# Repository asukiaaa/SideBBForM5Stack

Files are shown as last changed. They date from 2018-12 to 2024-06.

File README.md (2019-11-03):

# SideBBForM5Stack

An stack for M5Stack to use bread board easier.

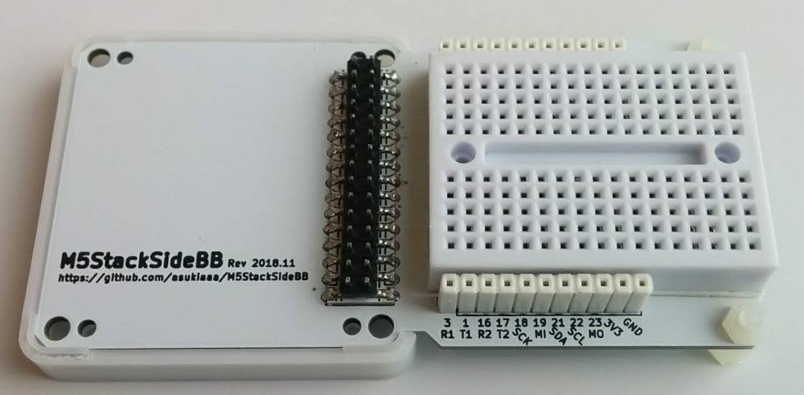
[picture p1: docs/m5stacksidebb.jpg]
m5stacksidebb

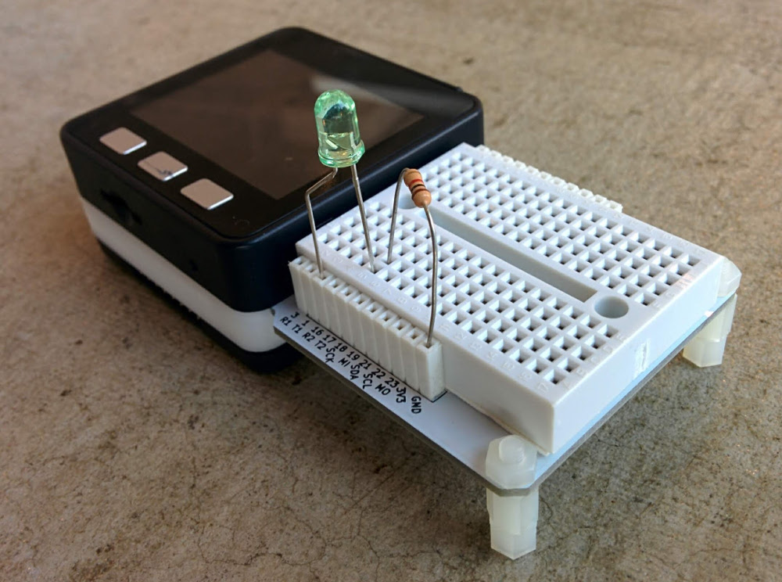
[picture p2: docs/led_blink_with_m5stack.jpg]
led_blink_with_m5stack


# Where to buy

[SideBBForM5Stack - Switch Science](https://www.switch-science.com/catalog/4098/)

# License

MIT

# References

- [M5Stackの信号線をブレッドボードで扱いやすくするStackを作ってみた](https://asukiaaa.blogspot.com/2018/11/m5stacksidebb.html)
- [PartsandCircuits/M5Stack-3DPrintFiles](https://github.com/PartsandCircuits/M5Stack-3DPrintFiles)
- [DIY Mini Proto Board](http://forum.m5stack.com/topic/59/diy-mini-proto-board)

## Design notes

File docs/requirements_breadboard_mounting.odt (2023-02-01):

Remove connectors on a bread board if it has hooks.

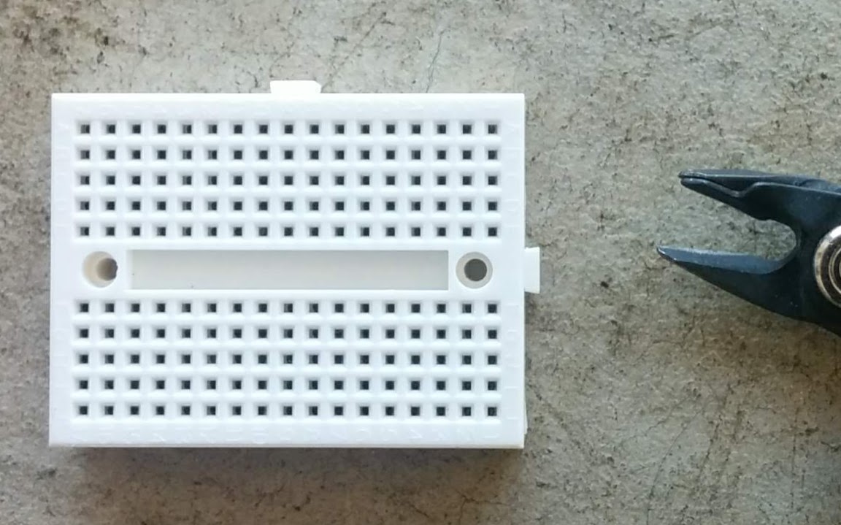
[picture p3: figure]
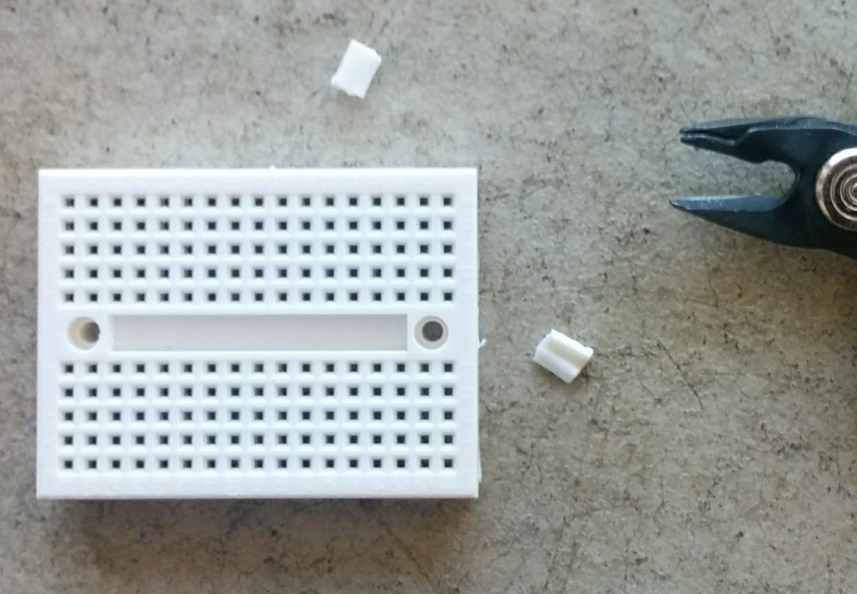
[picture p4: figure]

Put the bread board between pin sockets.

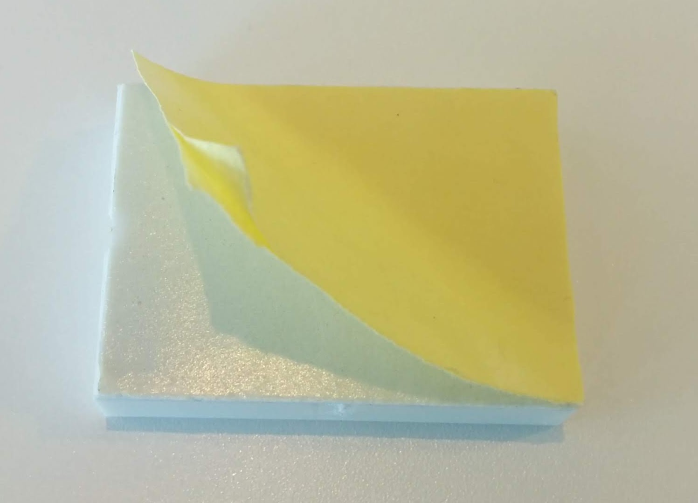
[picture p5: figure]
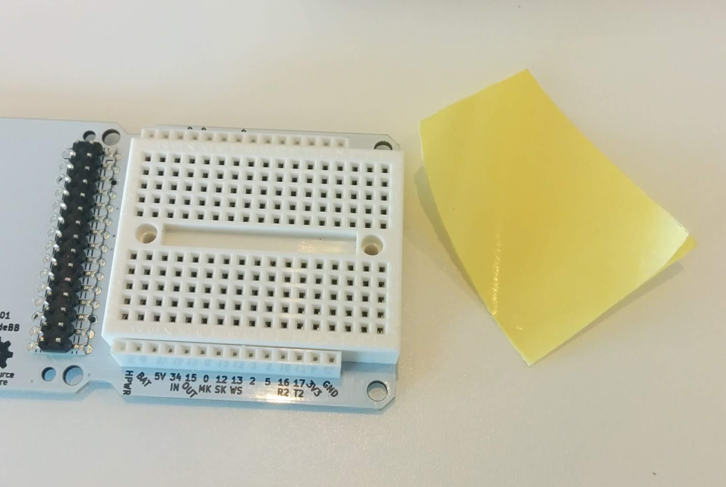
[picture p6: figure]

Make sure the hole position of pin sockets and bread board are parallel.

Be careful not to shift over 0.7mm.

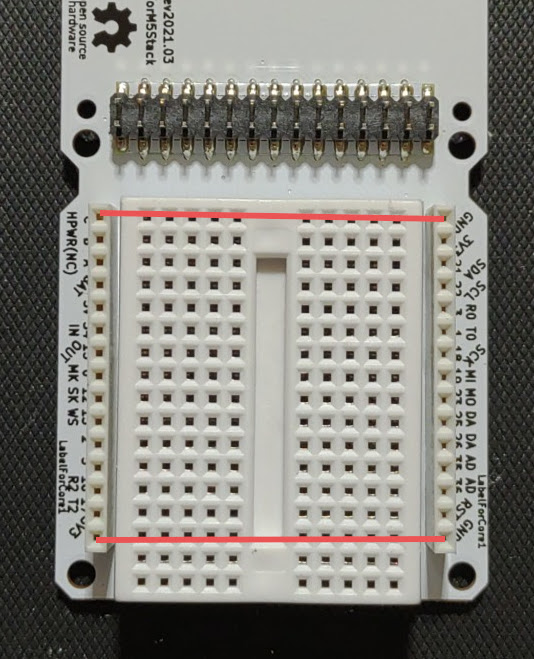
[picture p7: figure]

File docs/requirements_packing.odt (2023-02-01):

Put a frame on PCB.(Make sure that wall that has a depression become inside of PCB.)

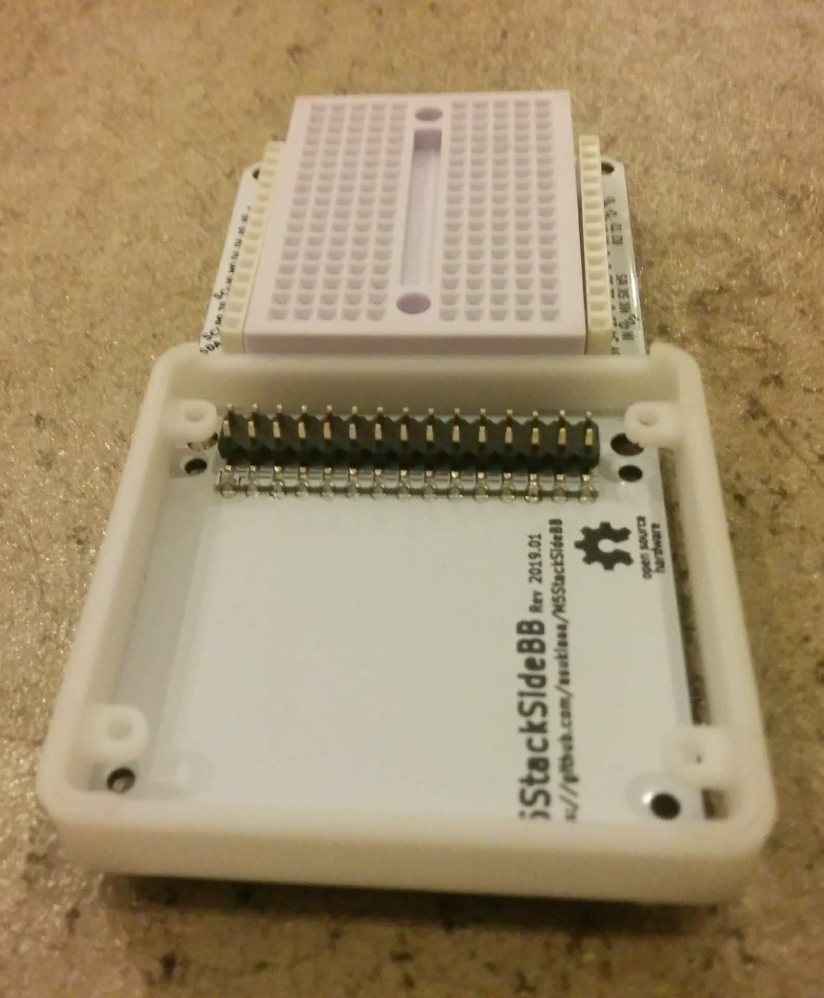
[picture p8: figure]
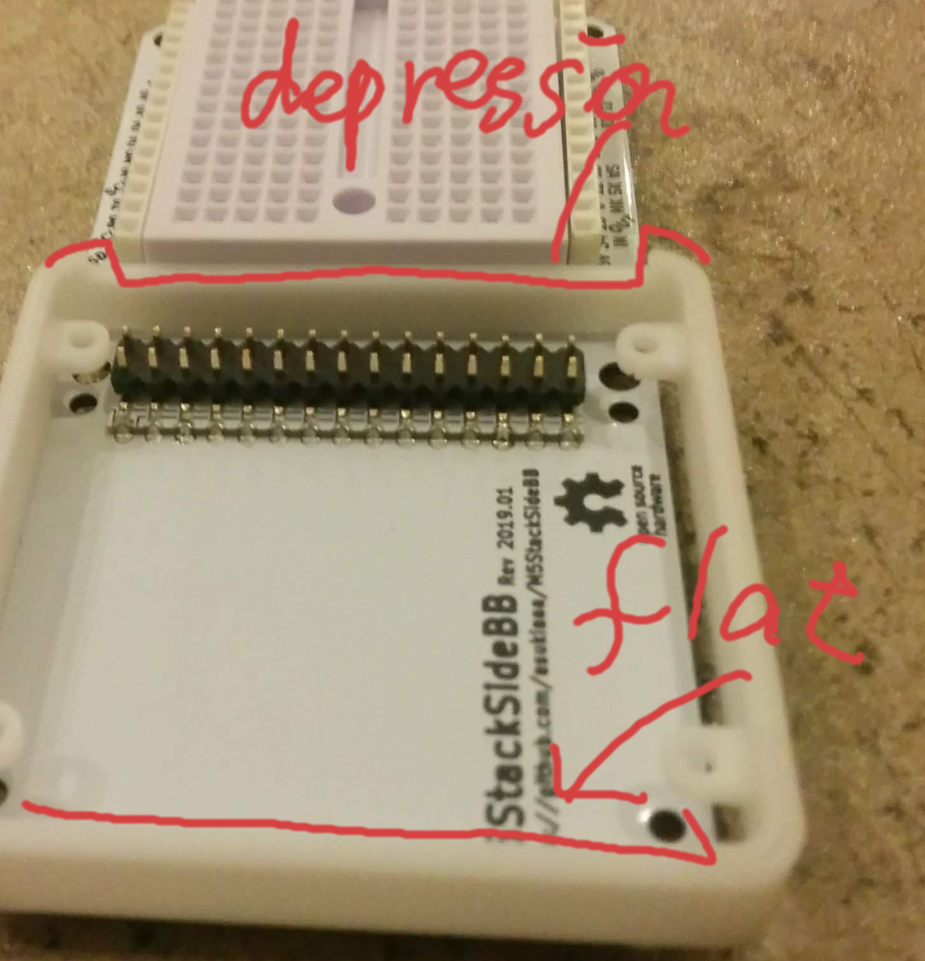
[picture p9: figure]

Put nuts(M3 *2) and spacers(M3 5mm * 2, M3 7mm * 2) inside of a frame.

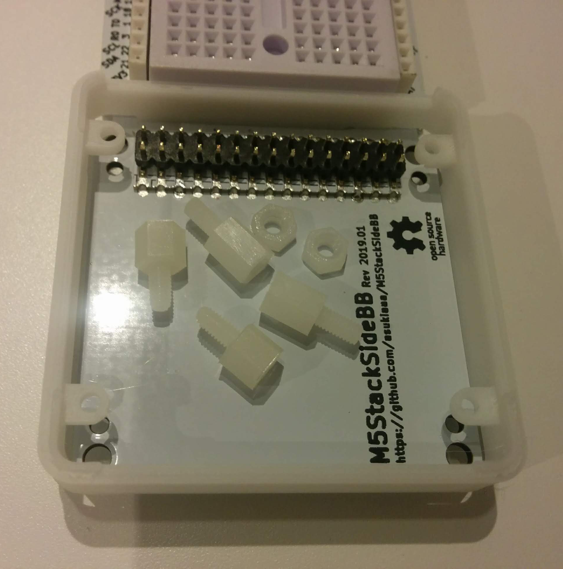
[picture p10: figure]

Put the pcb, frame, nuts and spacers into bug.

No need to close with some tape

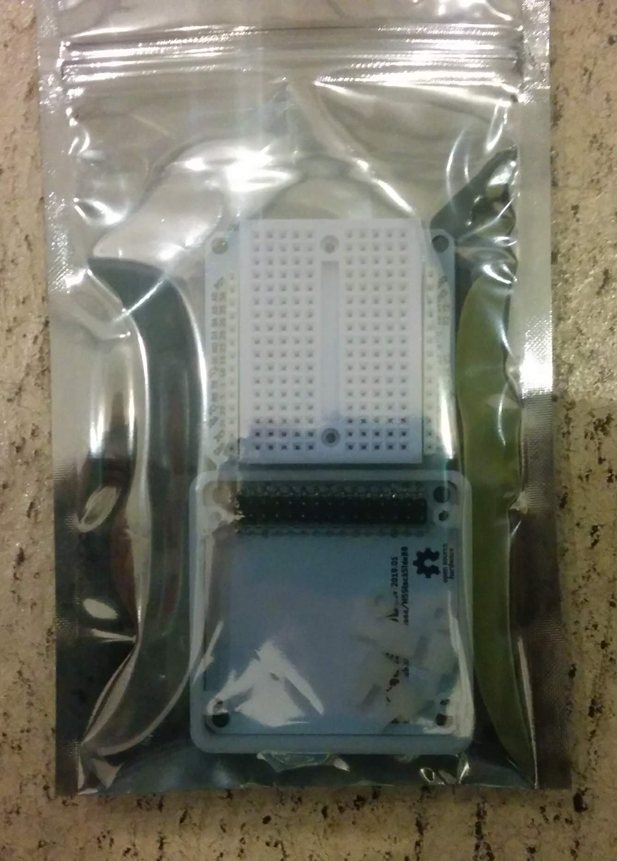
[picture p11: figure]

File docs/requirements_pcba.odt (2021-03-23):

M5StackSideBB Requirements.

Remove redundant copper from the spacer PCB.

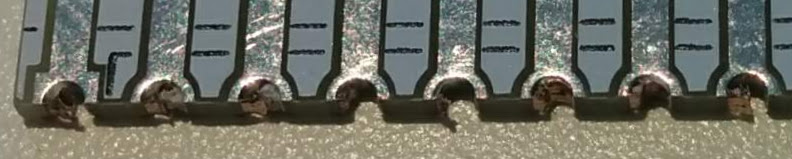
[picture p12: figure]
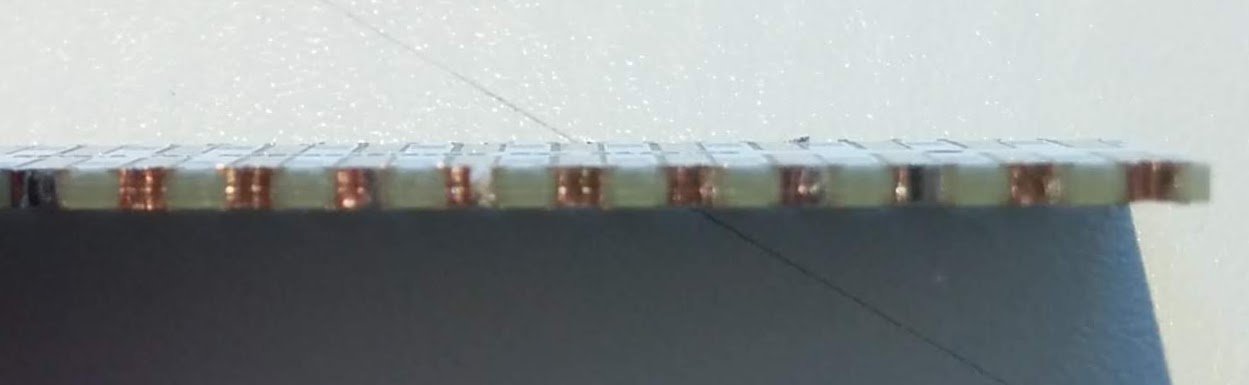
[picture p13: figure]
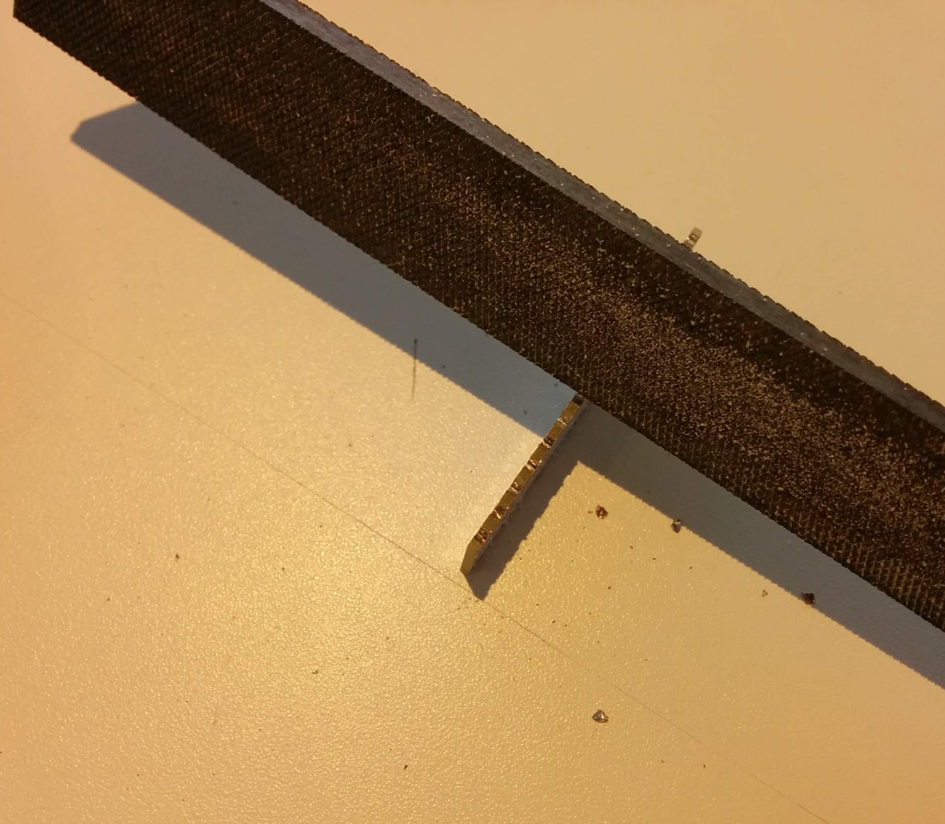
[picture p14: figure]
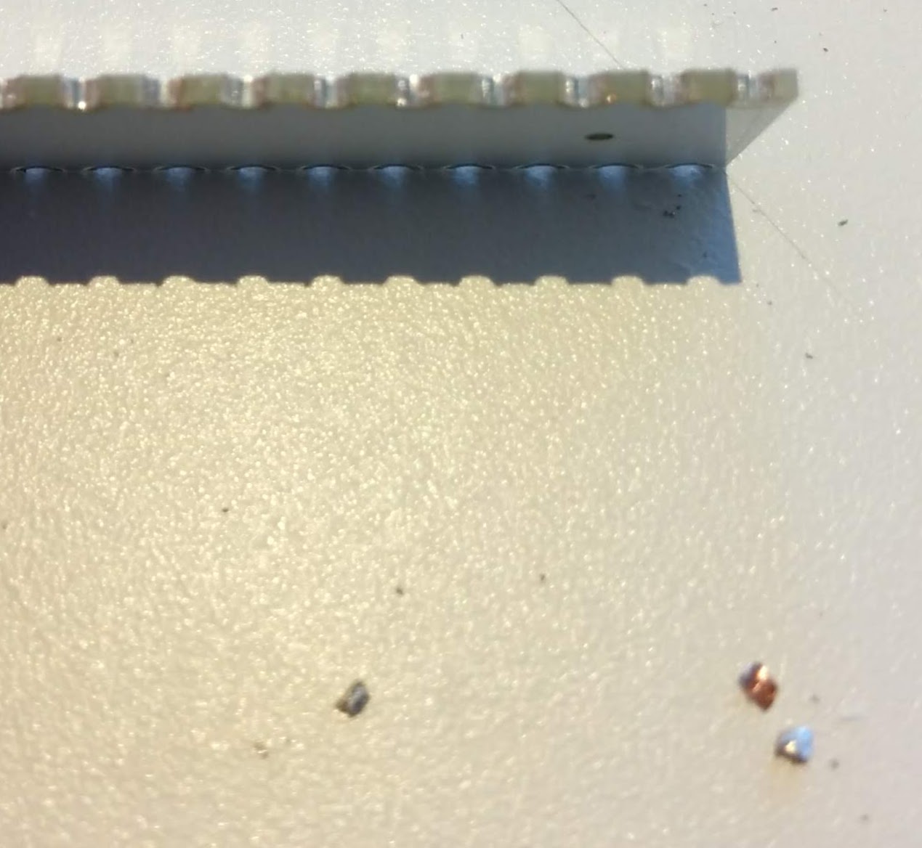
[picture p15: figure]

Adjust the hole positions of the spacer PCB and the main PCB, then solder to join them.

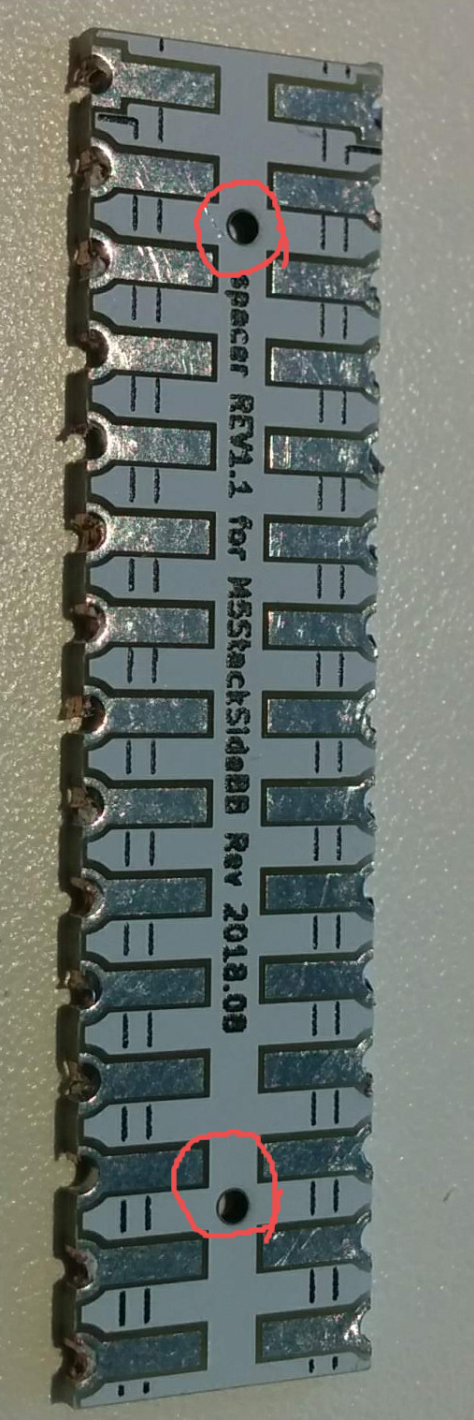
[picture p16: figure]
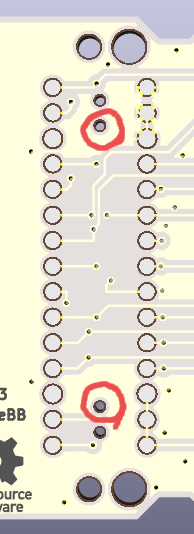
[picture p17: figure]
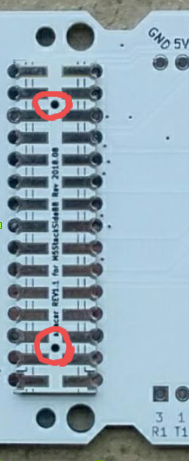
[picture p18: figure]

After that solder header to top, socket to bottom.

Put both pin sockets to inside of PCB as well as possible.

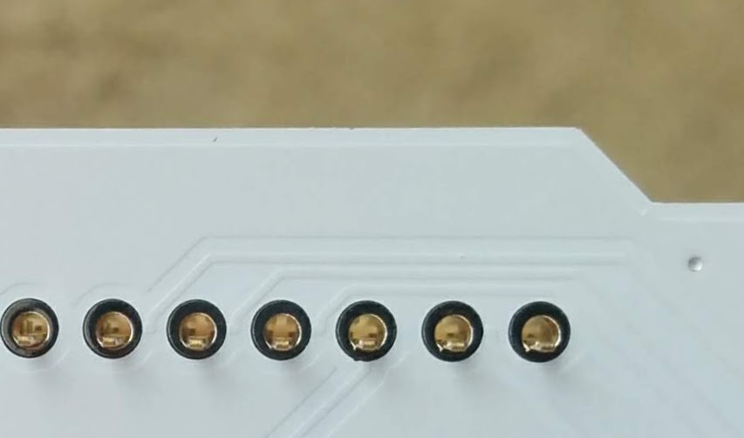
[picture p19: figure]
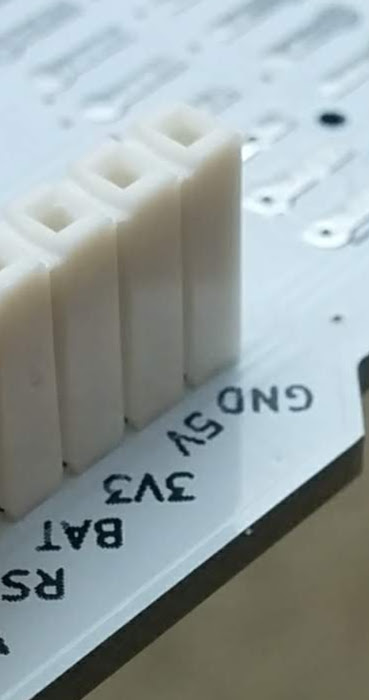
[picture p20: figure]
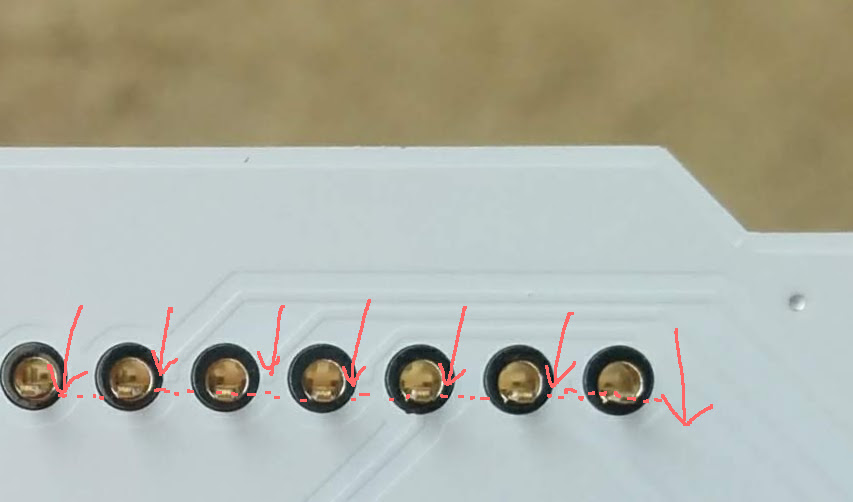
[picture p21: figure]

Finish images (Rev2021.03 uses 1x15 pinsocket)

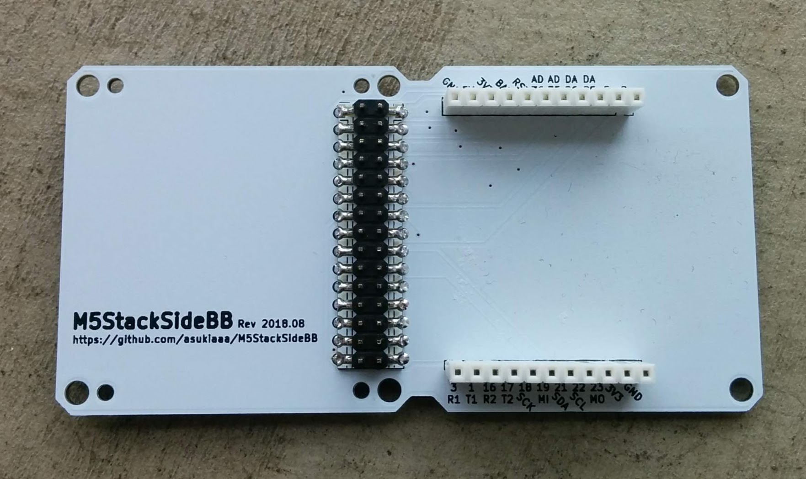
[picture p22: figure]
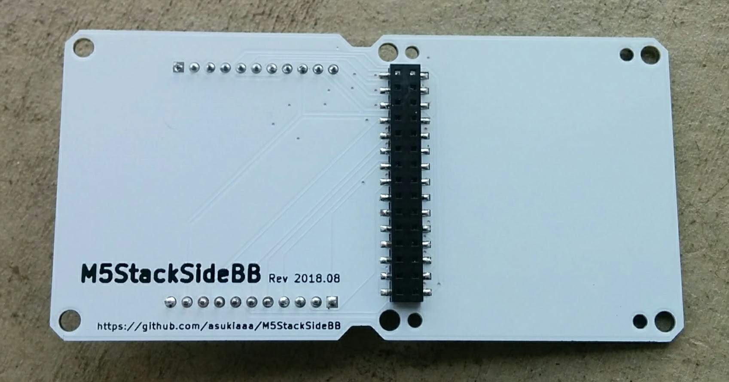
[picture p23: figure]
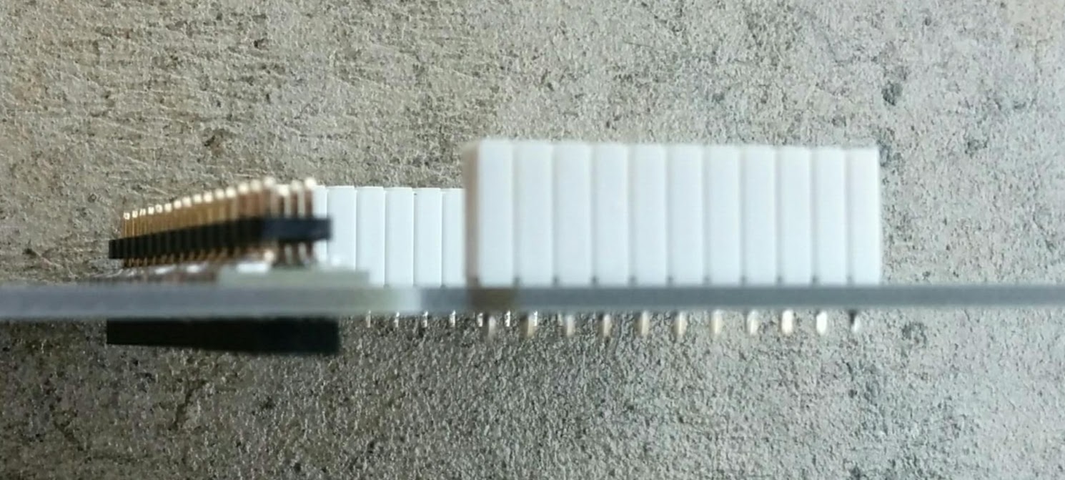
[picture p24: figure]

i

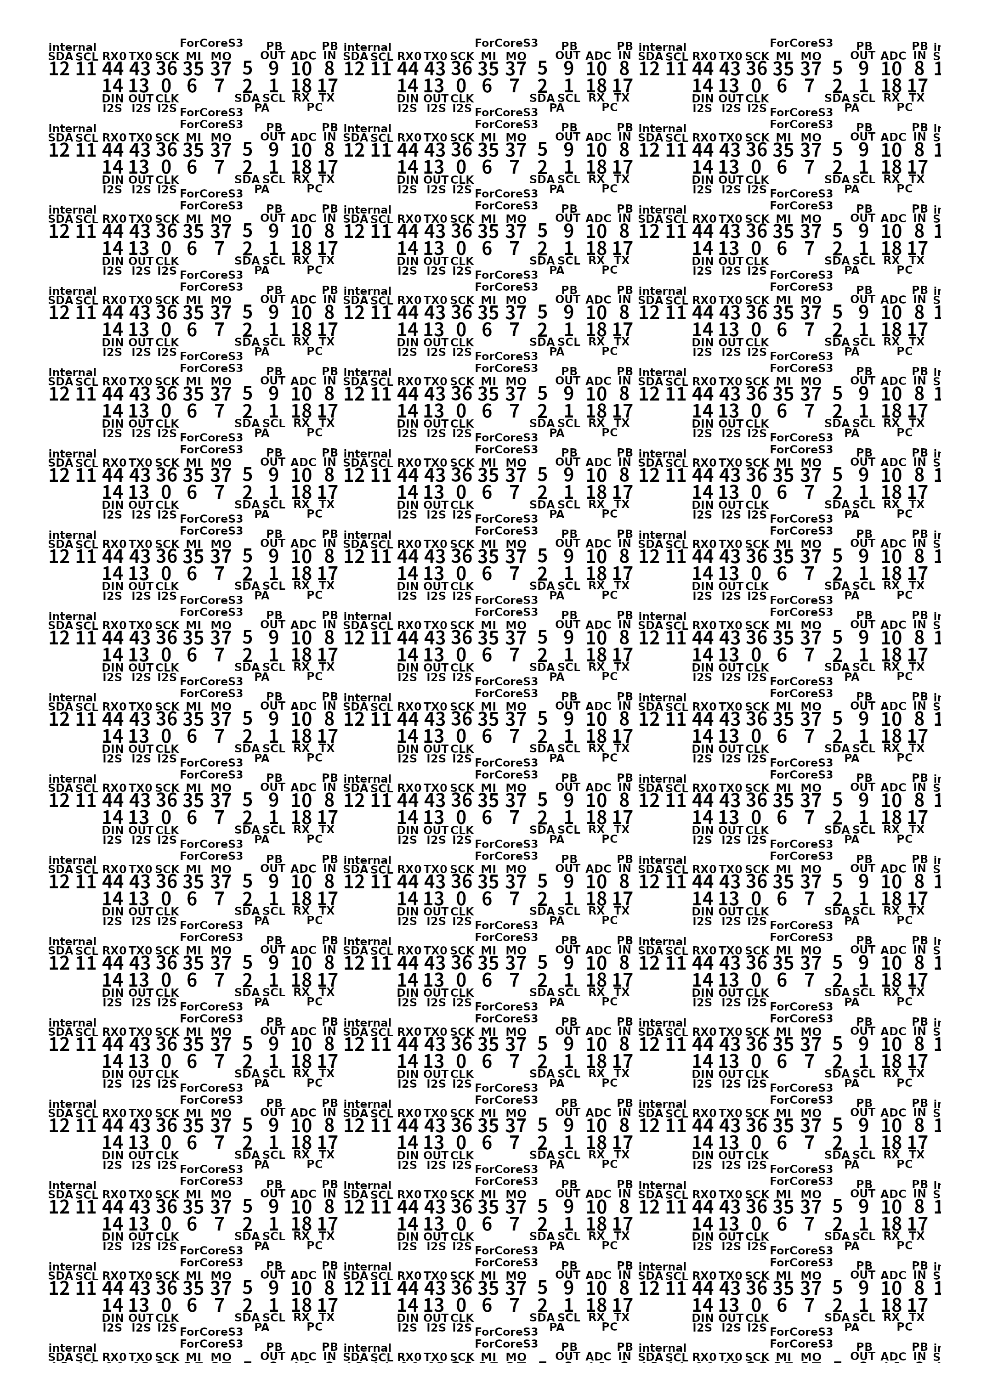
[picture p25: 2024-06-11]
docs/2148x3048px_tiles_of_lauson_sticker_l_2148x3048px_89x127mm_for_core_s3.png

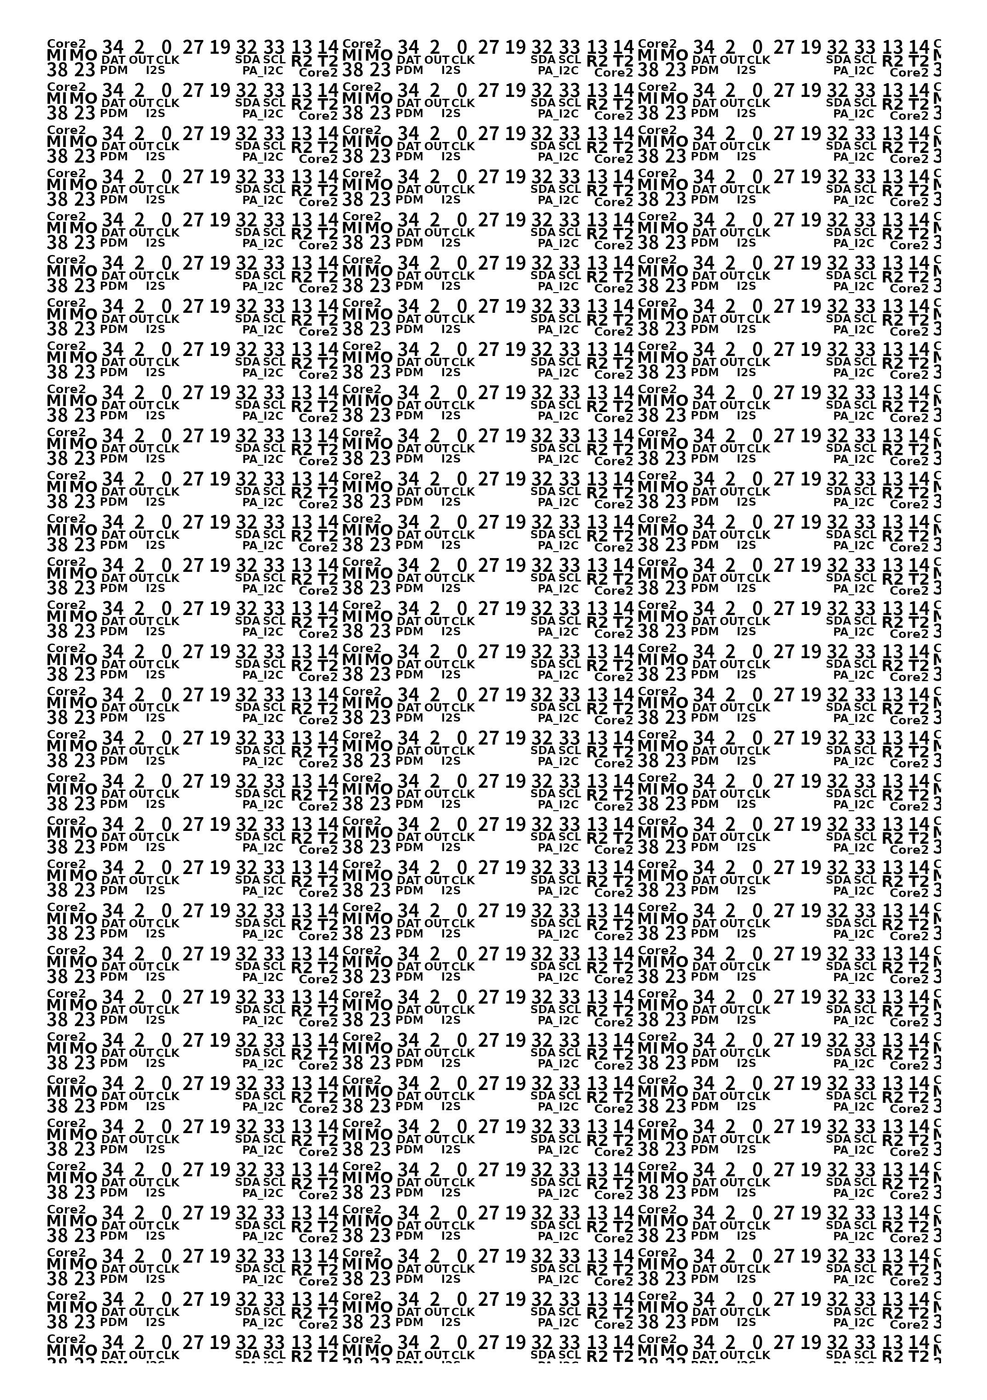
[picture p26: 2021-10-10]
docs/2148x3048px_tiles_for_core2.png

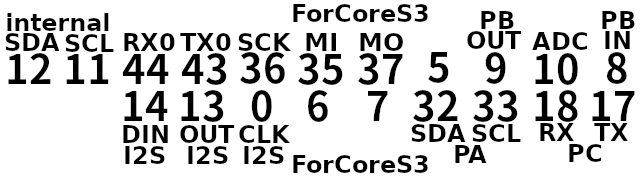
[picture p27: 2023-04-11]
docs/lauson_sticker_l_2148x3048px_89x127mm_for_core_s3.png

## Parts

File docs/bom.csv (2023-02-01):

Name | Number | Url | Memo
Main PCB (100x50x1.6mm) | 1 | Attached main
Spacer PCB (8.7x37.3x1.0mm) | 1 | Attached spacer
M5 Stack New(ver2021 about 6.5mm height) Header | 1 | https://shop.m5stack.com/collections/m5-accessories/products/2-%E2%9C%96-15-pinheader-bus-socket-smd-for-13-2-module-10-sets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
M5 Stack Legacy(before ver2021) Socket | 1 | https://shop.m5stack.com/collections/m5-accessories/products/2x15-pin-headers-socket
2.54mm 1x15 white socket | 2 | http://akizukidenshi.com/catalog/g/gC-11571/ | I don't mind the vendor.
MniBreadBoard white | 1 | https://ja.aliexpress.com/item/32972035565.html | Use this shop because quality of breadboard on Elecrow store was not good (on 2018.)
M3 5mm Spacer | 2 | https://ja.aliexpress.com/item/100pcs-M3-Nylon-Hexagonal-Pillar-Female-and-Male-Standoff-Spacer-M3x5-6mmm-M3x6-6mm-M3x7-6mm/32811270025.html | I don't mind the vendor.
M3 7mm Spacer | 2 | https://ja.aliexpress.com/item/32957035974.html | I don't mind the vendor.
M3 Nut | 2 | https://ja.aliexpress.com/item/100pcs-M3-Nylon-Hexagonal-Pillar-Female-and-Male-Standoff-Spacer-M3x5-6mmm-M3x6-6mm-M3x7-6mm/32811270025.html | I don't mind the vendor.

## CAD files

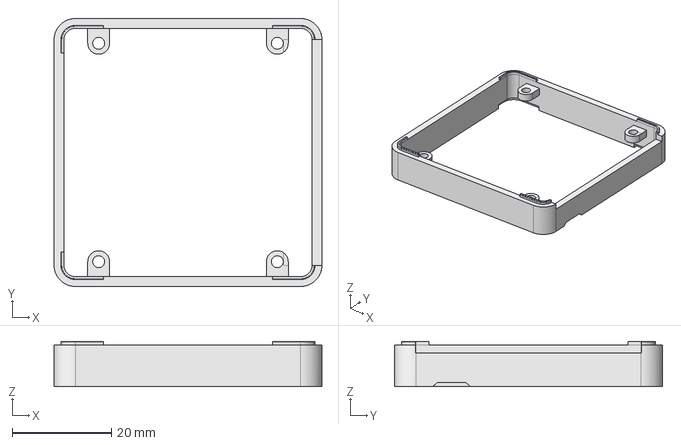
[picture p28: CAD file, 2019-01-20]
case/narrow/M5StackSideBBCase.fcstd
54.0 x 54.0 x 9.10 mm

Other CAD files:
case/zotrax_m200p/M5StackSideBBCase.fcstd
case/narrow/M5StackSideBBCase.stl
case/zotrax_m200p/M5StackSideBBCase.stl

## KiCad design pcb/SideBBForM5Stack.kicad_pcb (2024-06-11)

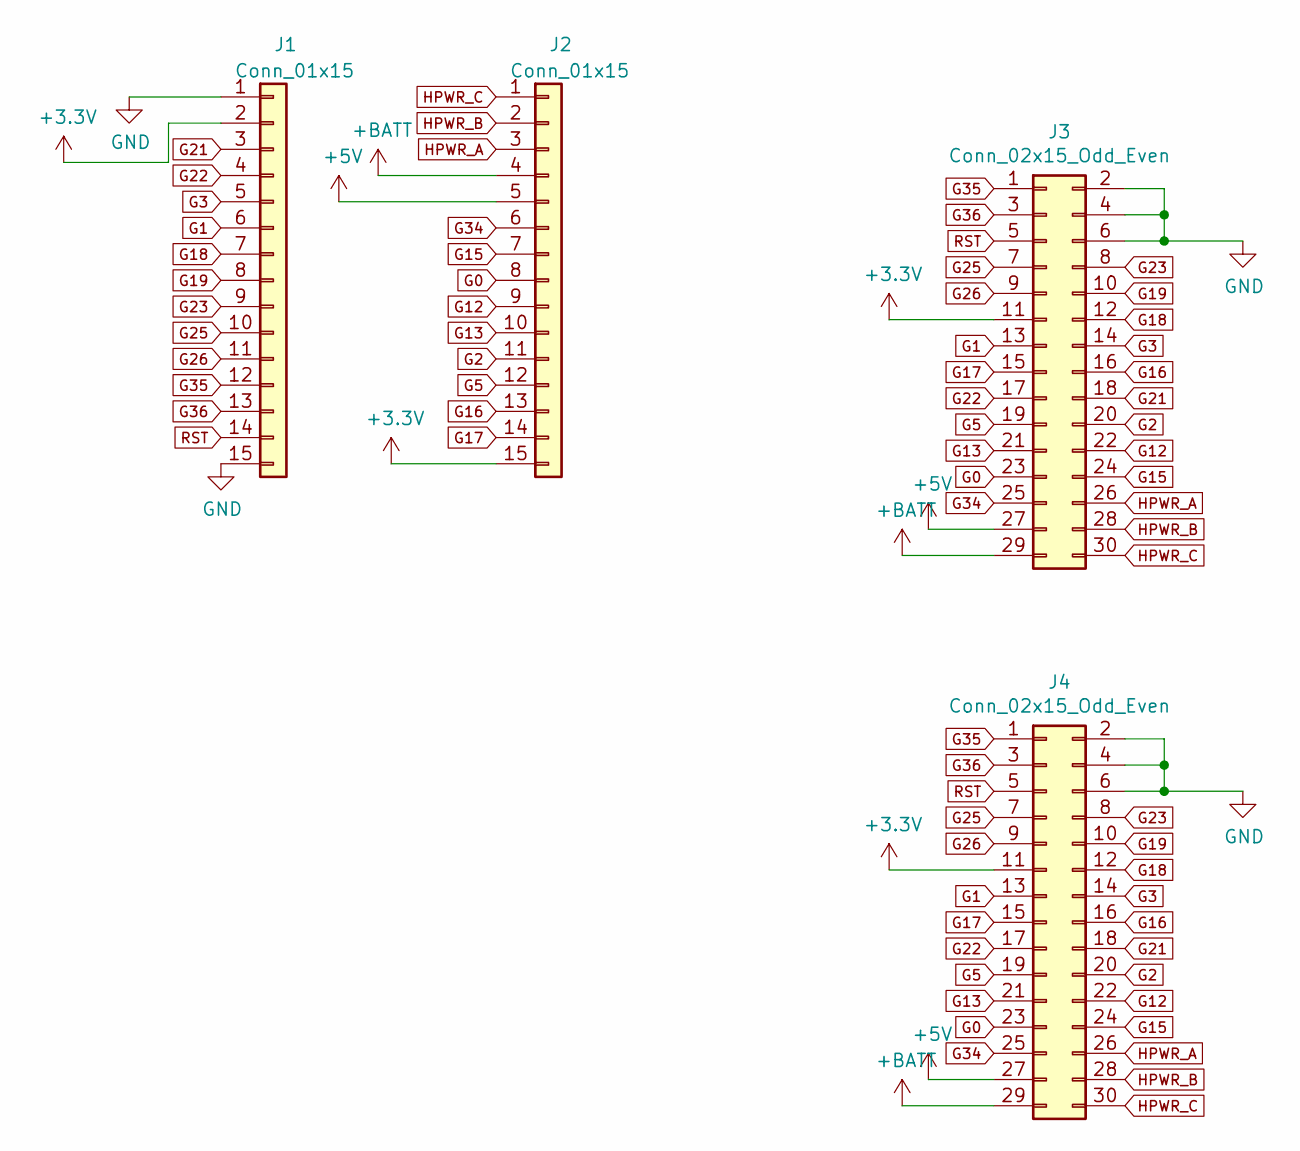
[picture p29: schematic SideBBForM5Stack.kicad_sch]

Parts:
J1, J2: Conn_01x15; PinSocket_1x15_P2.54mm_Vertical_without_silk
J3: Conn_02x15_Odd_Even; PinHeader_2x15_P2.54mm_M5Stack_SpacerPCB_pads
J4: Conn_02x15_Odd_Even; PinSocket_2x15_P2.54mm_Vertical_SMD_just_for_M5Stack_bottom

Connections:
+3V3: J1.2, J2.15, J3.11, J4.11
+5V: J2.5, J3.27, J4.27
+BATT: J2.4, J3.29, J4.29
G0: J2.8, J3.23, J4.23
G1: J1.6, J3.13, J4.13
G2: J2.11, J3.20, J4.20
G3: J1.5, J3.14, J4.14
G5: J2.12, J3.19, J4.19
G12: J2.9, J3.22, J4.22
G13: J2.10, J3.21, J4.21
G15: J2.7, J3.24, J4.24
G16: J2.13, J3.16, J4.16
G17: J2.14, J3.15, J4.15
G18: J1.7, J3.12, J4.12
G19: J1.8, J3.10, J4.10
G21: J1.3, J3.18, J4.18
G22: J1.4, J3.17, J4.17
G23: J1.9, J3.8, J4.8
G25: J1.10, J3.7, J4.7
G26: J1.11, J3.9, J4.9
G34: J2.6, J3.25, J4.25
G35: J1.12, J3.1, J4.1
G36: J1.13, J3.3, J4.3
GND: J1.1, J1.15, J3.2, J3.4, J3.6, J4.2, J4.4, J4.6
HPWR_A: J2.3, J3.26, J4.26
HPWR_B: J2.2, J3.28, J4.28
HPWR_C: J2.1, J3.30, J4.30
RST: J1.14, J3.5, J4.5

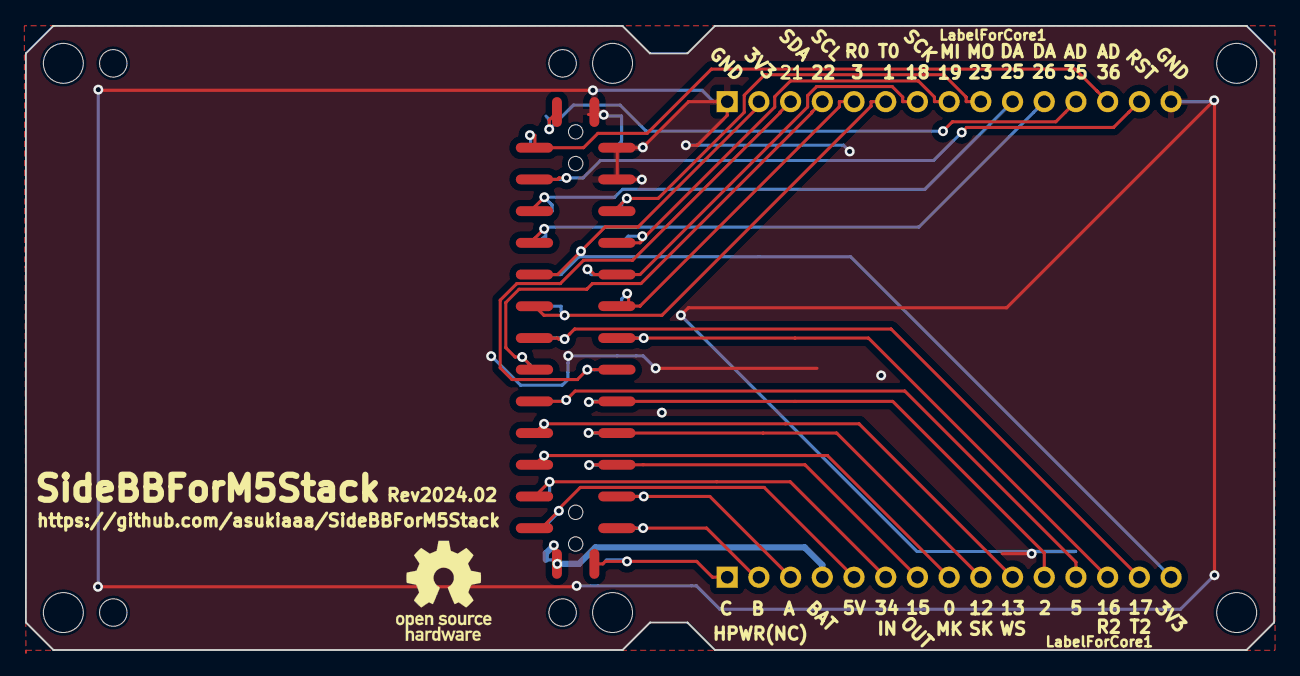
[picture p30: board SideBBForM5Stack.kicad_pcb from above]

Board: 2 copper layers, 100.0 x 50.0 mm, 14 parts (1 on the bottom side), 28 nets.

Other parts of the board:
REF1, REF4, REF5, REF6, REF9, REF10: MountingHole_3.2mm_M3
REF2, REF3, REF7, REF8: MountingHole_2.2mm_M2

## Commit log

2018-06-16 Create schematic of M5StackSideBB
    [M5StackSideBB.kicad_pcb, M5StackSideBB.sch]
2018-06-18 Put components and holes as pcb
    [M5StackSideBB.kicad_pcb, M5StackSideBB.sch]
2018-06-18 Draw lines with using autorouter
    [M5StackSideBB.kicad_pcb]
2018-06-18 Update schema and put silk texts
    [M5StackSideBB.kicad_pcb, M5StackSideBB.sch]
2018-06-19 Create gerber files to order
    [M5StackSideBB-B.Cu.gbr, M5StackSideBB-B.Mask.gbr, M5StackSideBB-B.Paste.gbr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]
2018-06-25 Create case in rough size
    [M5StackSideBBCase.fcstd]
2018-06-26 Adjust size by referencing M5Stack
    [M5StackSideBBCase.fcstd]
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2018-06-28 Update sylk layout of names about pins
    [M5StackSideBB.kicad_pcb, M5StackSideBBCase.fcstd]
2018-06-29 Update size of case
    [M5StackSideBBCase.fcstd, M5StackSideBBCase.stl]
2018-06-29 Update design of corner
    [M5StackSideBBCase.fcstd, M5StackSideBBCase.stl]
2018-06-30 Make top corner thicker and put inside
    [M5StackSideBBCase.fcstd, M5StackSideBBCase.stl]
2018-07-04 Change mounting hole size to M3 from M2.5
    [M5StackSideBB.kicad_pcb]
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2018-07-06 Create spacer pcb roughly
    [spacer_pcb.kicad_pcb, spacer_pcb.sch]
2018-07-07 Update connecting hole position between pcb and spacer pcb
    [M5StackSideBB.kicad_pcb, spacer_pcb.kicad_pcb]
2018-07-07 Update revision and gerbers
    [M5StackSideBB-B.Cu.gbr, M5StackSideBB-B.Mask.gbr, M5StackSideBB-B.Paste.gbr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]
2018-07-12 Change case height lower
    [M5StackSideBBCase.fcstd]
2018-07-13 Change low length shorter and top hook smaller
    [M5StackSideBBCase.fcstd]
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2018-07-17 Remove redundant reference on front fab
    [M5StackSideBB.kicad_pcb]
2018-07-18 Change space for breadborard narrower
    [M5StackSideBB.kicad_pcb]
2018-07-19 Change pinsocket on schema
    [M5StackSideBB.sch]
2018-07-19 Correct pin assign for bottom socket
    [M5StackSideBB.sch]
2018-07-20 Update component and its position on pcb
    [M5StackSideBB.kicad_pcb, M5StackSideBB.sch]
2018-07-20 Assign new footprint for spacer
    [spacer_pcb.kicad_pcb, spacer_pcb.sch]
2018-07-20 Update route of pcb
    [M5StackSideBB.kicad_pcb]
2018-07-21 Export gerber files to order rev 1.2
    [M5StackSideBB-B.Cu.gbr, M5StackSideBB-B.Mask.gbr, M5StackSideBB-B.Paste.gbr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]
2018-07-24 Expand clearance of top and bottom for case
    [M5StackSideBBCase.fcstd, M5StackSideBBCase.stl]
2018-07-26 Change back logo size larger
    [M5StackSideBB.kicad_pcb]
2018-07-27 Correct revision of spacer_pcb
    [spacer_pcb.kicad_pcb]
2018-10-05 Change innner size smaller
    [M5StackSideBBCase.fcstd, M5StackSideBBCase.stl]
2018-11-09 Update design for production
    [M5StackSideBB-B.Cu.gbr, M5StackSideBB-B.Mask.gbr, M5StackSideBB-B.Paste.gbr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]
2018-11-09 Change pad position as Rev 2018.11
    [M5StackSideBB-B.Cu.gbr, M5StackSideBB-B.Mask.gbr, M5StackSideBB-B.Paste.gbr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]
2018-11-17 Change bottom space to 1.0mm from 1.2mm
    [M5StackSideBBCase.fcstd]
2018-11-17 Change bottom length to 6.2mm from 6.5mm
    [M5StackSideBBCase.fcstd]
2018-11-17 Add space to remove for bottom area
    [M5StackSideBBCase.fcstd]
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2018-11-17 Update poition of a space to remove
    [M5StackSideBBCase.fcstd]
2018-11-17 Change space of bottom space to 1.1mm from 1.0mm
    [M5StackSideBBCase.fcstd]
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2018-11-17 Change bottom length 0.6mm longer
    [M5StackSideBBCase.fcstd, M5StackSideBBCase.stl]
2018-11-18 Change position of a space to remove as y9.5mm from y9.0mm
    [M5StackSideBBCase.fcstd, M5StackSideBBCase.stl]
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2018-12-02 Add 4 holes to detect position of spacer_pcb
    [M5StackSideBB.kicad_pcb]
2018-12-02 Add open source hardware logo
    [M5StackSideBB.kicad_pcb]
2018-12-02 Assign footprint of pin socket without silk
    [M5StackSideBB.kicad_pcb, M5StackSideBB.sch]
2018-12-02 Change GND via position arround G2
    [M5StackSideBB.kicad_pcb]
2018-12-02 Update revision as 2018.12
    [M5StackSideBB.kicad_pcb]
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2018-12-16 Correct UART number for G1 and G3
    [M5StackSideBB.kicad_pcb]
2018-12-21 Use 14 pins headers
    [M5StackSideBB.kicad_pcb, M5StackSideBB.sch]
2018-12-21 Remove redundant top pad
    [M5StackSideBB.kicad_pcb, M5StackSideBB.sch]
2018-12-21 Update revision as 2019.01
    [M5StackSideBB.kicad_pcb]
2018-12-21 Remove redundant info from spacer pcb
    [spacer_pcb.kicad_pcb]
2019-01-20 Add requirements for pcba
    [bom.csv]
2019-01-20 Craete directory of case for zotrax m200plus
    [M5StackSideBBCase.fcstd, M5StackSideBBCase.stl]
2019-01-20 Add narrow inner size case
    [M5StackSideBBCase.fcstd, M5StackSideBBCase.stl]
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2019-03-14 Change footprint for top pad without THT holes
    [M5StackSideBB.kicad_pcb, M5StackSideBB.sch]
2019-03-14 Update revision as 2019.03
    [M5StackSideBB.kicad_pcb]
2019-03-14 Update gerbers for main pcb
    [M5StackSideBB-B.Cu.gbr, M5StackSideBB-B.Mask.gbr, M5StackSideBB-B.Paste.gbr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]
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2019-05-03 Apply smaller pads for top and bottom
    [M5StackSideBB.kicad_pcb, M5StackSideBB.sch]
2019-05-05 Change link for breadboard on bom.csv
    [bom.csv]
2019-05-05 Add bottom pads for spacer PCB
    [M5StackSideBB.kicad_pcb, M5StackSideBB.sch, spacer_pcb.kicad_pcb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]
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2019-05-12 Correct y center position for smd pads
    [M5StackSideBB.kicad_pcb, bom.csv]
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2019-08-21 Update as narrow long style for pcb to spacer pads
    [M5StackSideBB.kicad_pcb, spacer_pcb.kicad_pcb]
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2021-03-28 Add label to mension that the labels for Core1
    [SideBBForM5Stack.kicad_pcb]
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2023-03-18 Correct revision on back silks
    [SideBBForM5Stack.kicad_pcb]
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2023-12-27 Move header and socket position 0.03mm inside as rev2024.01
    [SideBBForM5Stack.kicad_pcb, SideBBForM5Stack.kicad_sch]
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
